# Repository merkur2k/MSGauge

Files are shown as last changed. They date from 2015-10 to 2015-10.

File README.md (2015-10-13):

MegaSquirt CANbus gauge
==================

This is a simple single gauge for the [MegaSquirt](http://www.msextra.com/) Engine Controller.
It connects via CANbus and can output either via a 1.3" OLED display
or a small Switec X25 series stepper motor gauge needle driver.

It is built using the ARM [mbed](https://www.mbed.com/en/) platform, or more specicically a
port of it to GCC - [gcc4mbed](https://github.com/adamgreen/gcc4mbed/).

Quick start:
-----------
```
git clone https://github.com/merkur2k/MSGauge.git
cd MSGauge
git clone https://github.com/adamgreen/gcc4mbed.git
```
Follow the instructions at https://github.com/adamgreen/gcc4mbed/ to build gcc4mbed for your platform.
Build one of the gauge types:
```
cd MSGauge_OLED
make
```
or
```
cd MSGauge_Stepper
make
```
Use an ISP utility such as flash Magic (Windows) or lpc21isp (Linux) to flash the .bin or .hex in the LPC11C24 folder.

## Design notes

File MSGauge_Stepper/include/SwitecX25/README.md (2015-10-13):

Switec X25 library
==================

This is an mbed library for driving Switec X25 miniature
stepper motors. It was written specifically for the Switec X25.168,
and compatible steppers from other manufacturers including the
VID29 and MCR1108.

This was ported from an [Arduino version](https://github.com/clearwater/SwitecX25).

For more information including [datasheets](http://guy.carpenter.id.au/gaugette/resources) see the [Gaugette blog](http://guy.carpenter.id.au/gaugette/).

Usage Notes
-----------
This library assumes you are driving the X25 from any four IO lines,
via an intermediate controller circuit (any dual H-bridge driver).
A motor can be connected to any 4 digital output lines.

The rate at which these miniature stepper motors
can accelerate is dependent upon the inertia
of the needle you are using.  You may need to tune the acceleration
tables in the library for your needle.

This Library Is ASYNCHRONOUS NON-BLOCKING
-----------------------------------------
If you read nothing more, please read and understand this:

The ```update()``` call is _non-blocking_.  It does _NOT_ move
the motor to the target position, it advances the motor _at most
just one step_ toward the target position and returns.

The correct way to use this library asynchronously is:

- Add a call to ```update()``` inside your main loop.  It should be called as frequently as possible.  It will return quickly if there is nothing to be done.  This means for example if you are waiting for serial I/O, you should be calling ```update()``` while you are waiting.

- Call ```setPosition()``` whenever you need to change the target position of the motor.

The advantage of this over a blocking/synchronous library is that you can
control many motors simultanously, and you wont have long periods of inactivity
(and potentially missed I/O events) while your motor is moving.

If instead you require a blocking call which will complete the motor action before returning:

- Call ```setPosition()``` to to the target position of the motore

- Call ```updateBlocking()``` which will move the motor smoothy to the position set by ```setPosition()```.

Using the Library
-----------------

```C++
#include "SwitecX25.h"

// 315 degrees of range = 315x3 steps = 945 steps
// declare motor1 with 945 steps on pins 4-7
SwitecX25 motor1(315*3, P4,P5,P6,P7);

// declare motor2 with 945 steps on pins 8-11
SwitecX25 motor2(315*3, P8,P9,P10,P11);

printf("Go!\r\n");

// run both motors against stops to re-zero
motor1.zero();   // this is a slow, blocking operation
motor2.zero();  
motor1.setPosition(427);
motor2.setPosition(427);

void main(void) {
  // update motors frequently to allow them to step
  motor1.update();
  motor2.update();

  // do stuff, call motorX.setPosition(step) to
  // direct needle to new position.
}

```

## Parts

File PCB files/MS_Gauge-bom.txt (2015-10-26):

Part  Value          Device                Package                     Description                    
B1    ISP            SWITCH_TACT_SMTEVQPQ  BTN_EVQPQ_4.5MM             SMT Tact Switches                  http://www.mouser.com/ProductDetail/Panasonic/EVQ-PQHB55/?qs=%2fha2pyFadujeZOYETOiTVaMULyp0EOOpTFQossK0Vzk%3d
B2    ISP            SWITCH_TACT_SMTEVQPQ  BTN_EVQPQ_4.5MM             SMT Tact Switches                  http://www.mouser.com/ProductDetail/Panasonic/EVQ-PQHB55/?qs=%2fha2pyFadujeZOYETOiTVaMULyp0EOOpTFQossK0Vzk%3d
C1    18pF           CAP_CERAMIC0603       0603                        Ceramic Capacitors                 http://www.mouser.com/ProductDetail/AVX/06035A180GAT2A/?qs=sGAEpiMZZMs0AnBnWHyRQE2IRmxFPR1e1Lyvkz4L%252bhQ%3d
C2    10pF           CAP_CERAMIC0603       0603                        Ceramic Capacitors                 http://www.mouser.com/ProductDetail/AVX/06031C103KAT2A/?qs=sGAEpiMZZMs0AnBnWHyRQE2IRmxFPR1ekNYS%2fLeHWG0%3d
C3    100nF          CAP_CERAMIC0603       0603                        Ceramic Capacitors                 http://www.mouser.com/ProductDetail/AVX/06035C104KAT2A/?qs=sGAEpiMZZMs0AnBnWHyRQE2IRmxFPR1ePtLkvMARri4%3d
C4    10nF           CAP_CERAMIC0603       0603                        Ceramic Capacitors             
C5    100nF          CAP_CERAMIC0603       0603                        Ceramic Capacitors             
C6    10nF           CAP_CERAMIC0603       0603                        Ceramic Capacitors             
C7    10uF           CAP_CERAMIC1206       1206                        Ceramic Capacitors                 http://www.mouser.com/ProductDetail/Murata-Electronics/GCM31CC71E106KA03L/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
C8    10uF           CAP_CERAMIC1206       1206                        Ceramic Capacitors             
D1                   DIODESMA              SMADIODE                    Diode                              http://www.mouser.com/ProductDetail/STMicroelectronics/STTH102AY/?qs=EkbspN8Z2F35MrbgcZPHsw%3d%3d
IC1   B1836M         B1836M                MFP14S                                                         http://www.mouser.com/ProductDetail/ON-Semiconductor/LB1836ML-TLM-E/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
IC2   LPC11C24_QFP48 LPC11C24_QFP48        LQFP48                                                         http://www.mouser.com/ProductDetail/NXP-Semiconductors/LPC11C24FBD48-301/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
IC3   24LC32AT-I/OT  24LC32AT-I/OT         SOT23-5L                                                       http://www.mouser.com/ProductDetail/Microchip-Technology/24LC32AT-I-OT/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
JP1                  HEADER-1X4ROUND       1X04_ROUND                  PIN HEADER for OLED, 2x required   http://www.mouser.com/ProductDetail/Molex/87898-0426/?qs=sGAEpiMZZMs%252bGHln7q6pm8NDWwBzqQCN6n%2fkr6CupYg%3d                    
JP2   ISP            HEADER-1X6SMT         1X06_SMT                    PIN HEADER for ISP serial          http://www.mouser.com/ProductDetail/Molex/87898-0626/?qs=sGAEpiMZZMs%252bGHln7q6pm8NDWwBzqQCN6ivodECCTq8%3d
LED2                 LED0603               CHIPLED_0603                LED     
R1    120            RESISTOR0603          0603                        Resistors                          http://www.mouser.com/ProductDetail/Panasonic/ERJ-3GEYJ121V/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
R2    120            RESISTOR0603          0603                        Resistors                        
R3    10k            RESISTOR0603          0603                        Resistors                        
R4    10k            RESISTOR0603          0603                        Resistors                        
R7    4.7k           RESISTOR0603          0603                        Resistors                        
R8    4.7k           RESISTOR0603          0603                        Resistors  
U$1   VID29-FLIPPED  VID29-FLIPPED         VID29-FLIPPED               Switec X27.168 motor               ebay, etc                
U$18  OLED-SMT       OLED-SMT              OLED-1.3-SMT                Uses 2x 4 pos pin header           http://www.mouser.com/ProductDetail/Molex/87898-0426/?qs=sGAEpiMZZMs%252bGHln7q6pm8NDWwBzqQCN6n%2fkr6CupYg%3d                        
U1                   VREG_SOT23            SOT23-R                     SOT23 Fixed Voltage Regulators     http://www.mouser.com/ProductDetail/Microchip-Technology/MCP1700T-3302E-TT/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
U2    TSR1-2450      TSR1-2450             TSR-1                       Traco Power TSR 1-2450             http://www.mouser.com/ProductDetail/RECOM-Power/R-78E50-05/?qs=sGAEpiMZZMt6Q9lZSPl3Re5VKOUP6OK3oKGplDCSDFs%3d 
Y1    12MHz          CRYSTALTHIN           CRYSTAL_3.2X2.5             Crystals                           http://www.mouser.com/ProductDetail/ABRACON/ABM8G-12000MHZ-B4Y-T/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

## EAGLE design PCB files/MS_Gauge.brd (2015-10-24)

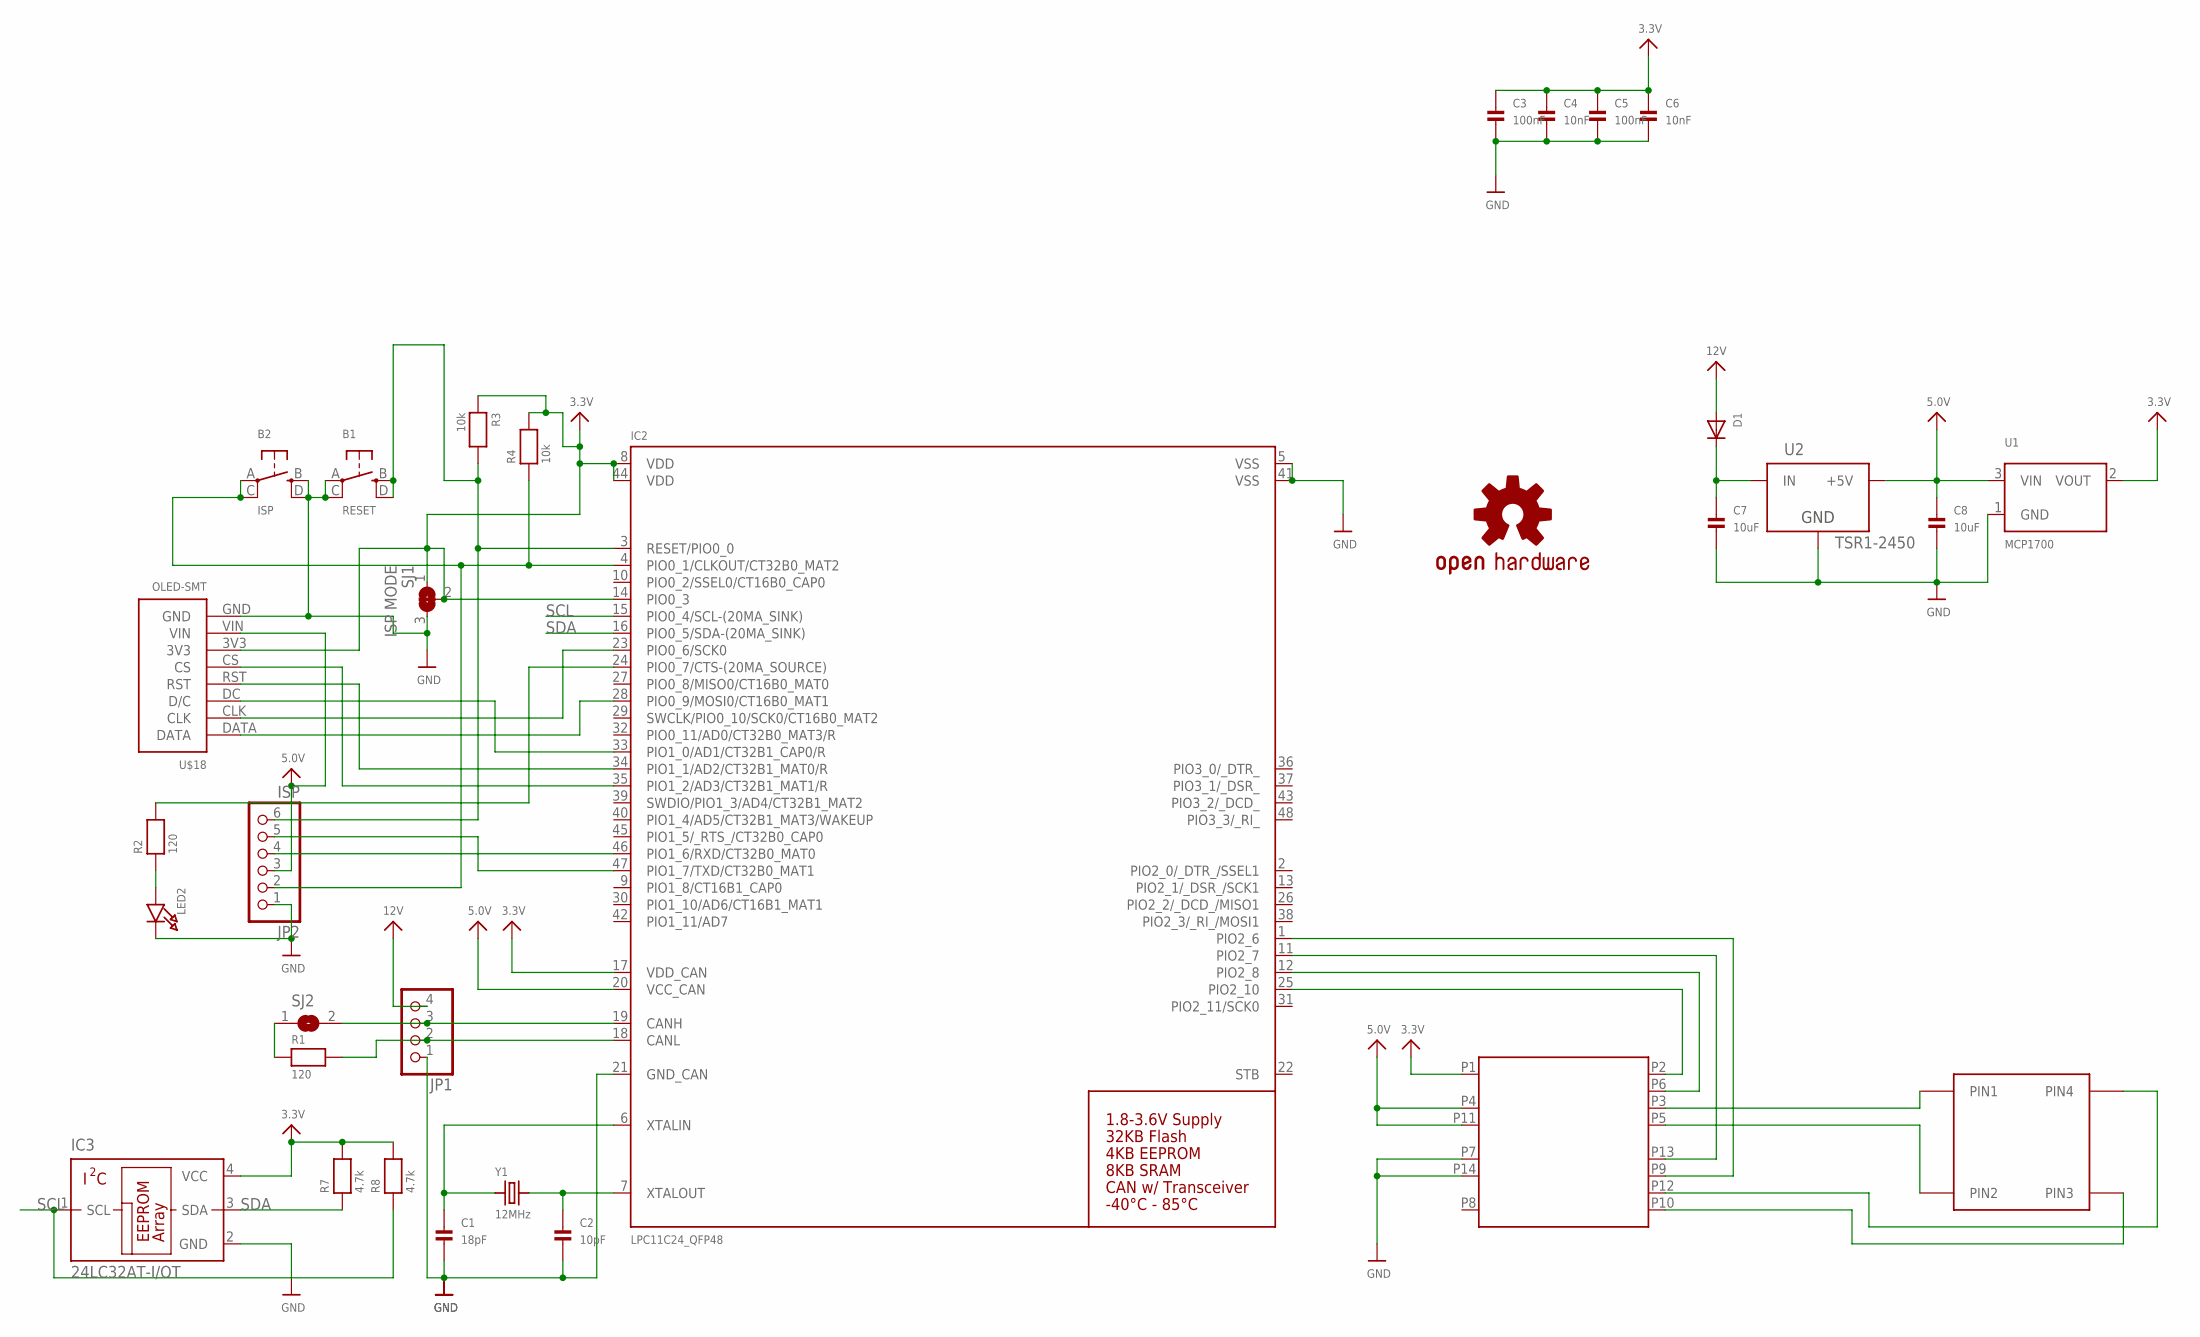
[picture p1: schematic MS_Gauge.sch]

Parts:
B1: RESET; BTN_EVQPQ_4.5MM
B2: ISP; BTN_EVQPQ_4.5MM
C1: 18pF; 0603
C2: 10pF; 0603
C3, C5: 100nF; 0603
C4, C6: 10nF; 0603
C7, C8: 10uF; 1206
D1: DIODESMA; SMADIODE
IC1: B1836M; MFP14S
IC2: LPC11C24_QFP48; LQFP48
IC3: 24LC32AT-I/OT; SOT23-5L
JP1: HEADER-1X4ROUND; 1X04_ROUND
JP2: ISP; 1X06_SMT
LED2: LED0603; CHIPLED_0603
LOGO1: OSHW-LOGOL; OSHW-LOGO-L
R1, R2: 120; 0603
R3, R4: 10k; 0603
R7, R8: 4.7k; 0603
SJ1: ISP MODE; SOLDERJUMPER_2WAY_OPEN_0805
SJ2: SOLDERJUMPER; SOLDERJUMPER_ARROW_NOPASTE
U1: MCP1700; SOT23-R
U2: TSR1-2450; TSR-1
U$1: VID29-FLIPPED
U$18: OLED-SMT; OLED-1.3-SMT
Y1: 12MHz; CRYSTAL_3.2X2.5

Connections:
3.3V: C3.1, C4.1, C5.1, C6.1, IC1.P1 (VCC), IC2.8 (VDD), IC2.14 (PIO0_3), IC2.17 (VDD_CAN), IC2.44 (VDD), IC3.4 (VCC), R3.1, R4.2, R7.2, R8.2, SJ1.1, SJ1.2, U1.2 (VOUT), U$18.3V3
5.0V: C8.1, IC1.P4 (VS1), IC1.P11 (VS2), IC2.20 (VCC_CAN), JP2.3, U1.3 (VIN), U2.3 (+5V), U$18.VIN
12V: D1.A, JP1.4
GND: B1.A, B1.C (P1), B2.B (S), B2.D (S1), C1.2, C2.2, C3.2, C4.2, C5.2, C6.2, C7.2, C8.2, IC1.P7 (GND1), IC1.P14 (GND2), IC2.5 (VSS), IC2.21 (GND_CAN), IC2.41 (VSS), IC3.2 (GND), JP1.1, JP2.1, LED2.C, SJ1.3, U1.1 (GND), U2.2 (GND), U$18.GND
unnamed: R1.1, SJ2.1
unnamed: IC2.18 (CANL), JP1.2, R1.2
unnamed: C2.1, IC2.7 (XTALOUT), Y1.2
unnamed: C1.1, IC2.6 (XTALIN), Y1.1
unnamed: B2.A, B2.C (P1), IC2.4 (PIO0_1/CLKOUT/CT32B0_MAT2), JP2.2, R4.1
unnamed: IC1.P2 (IN1), IC2.25 (PIO2_10)
unnamed: B1.B (S), B1.D (S1), IC2.3 (RESET/PIO0_0), JP2.6, R3.2
unnamed: IC1.P13 (IN3), IC2.11 (PIO2_7)
unnamed: IC1.P9 (IN4), IC2.1 (PIO2_6)
unnamed: IC1.P3 (OUT1), U$1.PIN1
unnamed: C7.1, D1.C, U2.1 (IN)
unnamed: IC1.P5 (OUT2), U$1.PIN2
unnamed: IC1.P12 (OUT3), U$1.PIN4
unnamed: IC1.P10 (OUT4), U$1.PIN3
unnamed: IC2.19 (CANH), JP1.3, SJ2.2
unnamed: IC2.46 (PIO1_6/RXD/CT32B0_MAT0), JP2.4
unnamed: IC2.47 (PIO1_7/TXD/CT32B0_MAT1), JP2.5
unnamed: IC2.28 (PIO0_9/MOSI0/CT16B0_MAT1), U$18.DATA
unnamed: IC2.33 (PIO1_0/AD1/CT32B1_CAP0/R), U$18.DC (D/C)
unnamed: IC2.34 (PIO1_1/AD2/CT32B1_MAT0/R), U$18.RST
unnamed: IC2.23 (PIO0_6/SCK0), U$18.CLK
unnamed: IC2.35 (PIO1_2/AD3/CT32B1_MAT1/R), U$18.CS
unnamed: IC2.24 (PIO0_7/CTS-(20MA_SOURCE)), R2.2
unnamed: LED2.A, R2.1
unnamed: IC1.P6 (IN2), IC2.12 (PIO2_8)
SCL: IC2.15 (PIO0_4/SCL-(20MA_SINK)), IC3.1 (SCL), R8.1
SDA: IC2.16 (PIO0_5/SDA-(20MA_SINK)), IC3.3 (SDA), R7.1

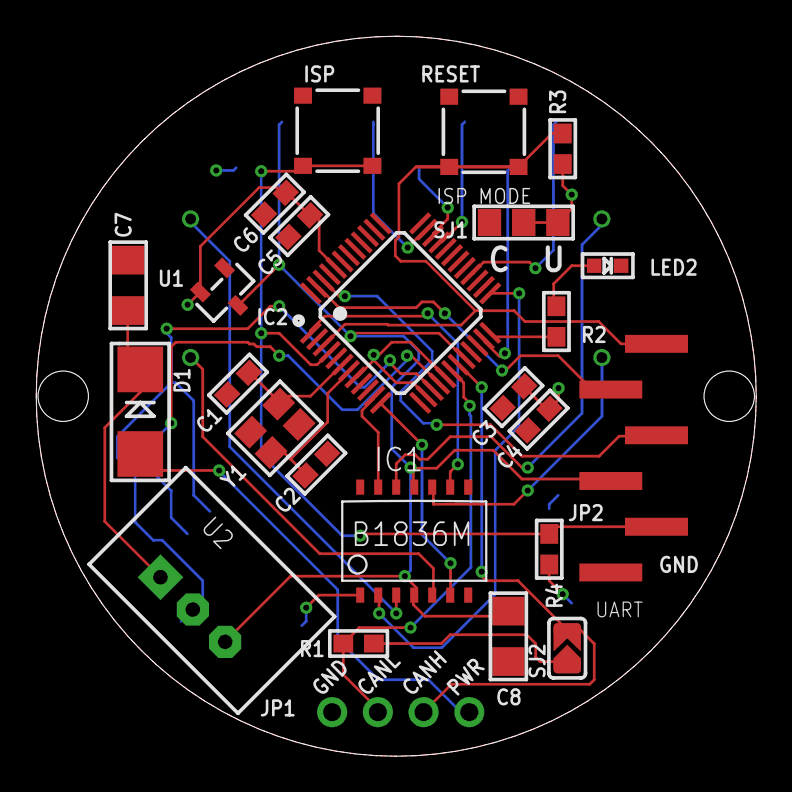
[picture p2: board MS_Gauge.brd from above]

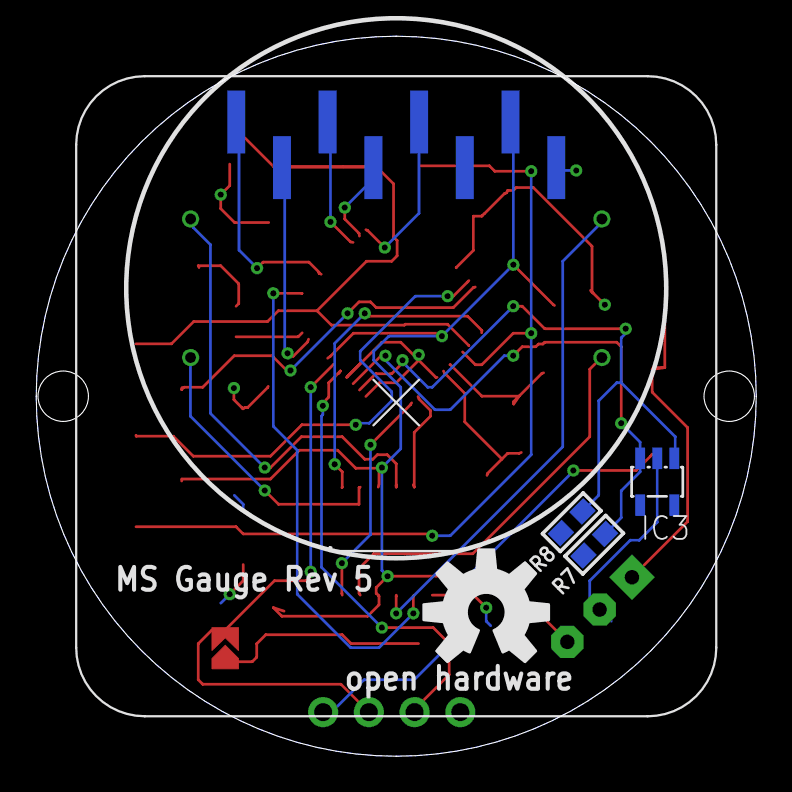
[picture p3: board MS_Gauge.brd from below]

Board: 2 copper layers, 40.0 x 40.0 mm, 31 parts (6 on the bottom side), 31 nets.

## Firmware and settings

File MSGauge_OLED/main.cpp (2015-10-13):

/*
 *  Copyright (c) 2015 Jason Richardson
 *
 *  License: MIT open source (http://opensource.org/licenses/MIT)
 *      Summary;
 *      Use / modify / distribute / publish it how you want and
 *      if you use it, or don't, you can't hold me liable for how
 *      it does or doesn't work.
 *      If it doesn't work how you want, don't use it, or change
 *      it so that it does work.
 */

#include "mbed.h"
#include "Gauge_config.h"
#include "include/SSD1306/Adafruit_SSD1306.h"

uint16_t value = 1;
Timer alarmTimer;
Timer commTimer;
Timer displayTimer;

#if defined(GAUGE_MAP)
uint16_t baro = 0;
#endif

char tempchars[11];

bool connectionState = true;
bool alarmDisplayStatus = false;

DigitalOut led2(LED2);
CAN can1(p9, p10);

// an SPI sub-class that provides a constructed default
class SPIPreInit : public SPI
{
public:
    SPIPreInit(PinName mosi, PinName miso, PinName clk) : SPI(mosi,miso,clk)
    {
        format(8,3);
        frequency(4000000);
    };
};

SPIPreInit gSpi(P0_9,P0_8,P0_6);
//                             DC,  RST, CS
Adafruit_SSD1306_Spi oled(gSpi,P1_0,P1_1,P1_2,64,128);

void divby10(int val) {
  uint8_t length;

  itoa(val, tempchars, 10);
  length=strlen(tempchars);

  tempchars[length + 1]=tempchars[length]; // null shift right
  tempchars[length]=tempchars[length - 1]; //
  tempchars[length - 1]='.';
}

// CAN receive interrupt handler
void canRX() {
  CANMessage msg;
  while(can1.read(msg)) {
    if (msg.id == 1522) {
      connectionState = true;
      commTimer.reset();
#if defined(GAUGE_CLT)
      value = msg.data[7] | (msg.data[6] << 8);
#elif defined(GAUGE_MAT)
      value = msg.data[5] | (msg.data[4] << 8);
#elif defined(GAUGE_MAP)
      value = msg.data[3] | (msg.data[2] << 8);
      baro = msg.data[1] | (msg.data[0] << 8);
#endif
      led2 = !led2;
    }
  }
}

void drawGauge(void) {
  oled.drawLine(0, 12, 12, 22, WHITE);
  oled.drawLine(20, 12, 28, 22, WHITE);
  oled.drawLine(40, 12, 45, 22, WHITE);
  oled.drawLine(88, 12, 83, 22, WHITE);
  oled.drawLine(108, 12, 100, 22, WHITE);
  oled.drawLine(128, 12, 116, 22, WHITE);
  oled.drawFastVLine(64, 12, 10, WHITE);

  oled.setTextSize(1);
  oled.setTextColor(WHITE);
#if defined(GAUGE_CLT)
  oled.setTextCursor(44,27);
  oled.printf("COOLANT");
  oled.setTextCursor(32,36);
  oled.printf("TEMPERATURE");
  oled.setTextCursor(0,0);
  oled.printf("COLD");
  oled.setTextCursor(47,0);
  oled.printf("NORMAL");
  oled.setTextCursor(110,0);
  oled.printf("HOT");
#elif defined(GAUGE_MAP)
  oled.setTextCursor(40,27);
  oled.printf("MANIFOLD");
  oled.setTextCursor(40,36);
  oled.printf("PRESSURE");
  oled.setTextCursor(0,0);
  oled.printf("0");
  oled.setTextCursor(60,0);
  oled.printf("10");
  oled.setTextCursor(116,0);
  oled.printf("20");
#endif
}

void drawNeedle(uint16_t value) {
  uint8_t level;
  uint16_t alarmValue = 0;

  // scale "value" to 1-128 and store it in "level", and set bounds for error condition
  // value * 128 / full_scale
#if defined(GAUGE_CLT)
  //value /= 10;
  // scale 160-260, alarm > 230
  if (value >= 1600) {
    level = (value / 10 - 160) * 128 / 70;
  } else {
    level = 0;
  }
  alarmValue = 2300;
  oled.setTextSize(2);
  oled.setTextCursor(36,48);
  //oled.printf("%4d.%1d",value/10,value%10);
#elif defined(GAUGE_MAT)
  value /= 10;
  if (value >= 160) {
    level = (value - 160) * 128 / 70;
  } else {
    level = 0;
  }
  oled.setTextSize(2);
  oled.setTextCursor(36,48);
  //oled.printf("%4d.%1d",value/10,value%10);
  divby10(value);
  oled.printf("%s",tempchars);

#elif defined(GAUGE_MAP)
  // assume 2.5 bar MAP sensor with forced induction
  // needle scales for boost only, 0-21ish psi
  if (value > baro) {
    // in boost. 6.895kpa = 1psi
    value = (value - baro) * 200 / 1379;
    level = value * 128 / 210;
    oled.setTextSize(2);
    oled.setTextCursor(52,48);
    //oled.printf("%2d.%1d",value/10,value%10);
    divby10(value);
    oled.printf("%s",tempchars);
    oled.setTextSize(1);
    oled.setTextCursor(104,56);
    oled.printf("psi");
  } else {
    // in vacuum. 1 kPa = 0.2953 in Hg
    level = 0;
    value = abs(baro - value) * 2953 / 10000;
    oled.setTextSize(2);
    oled.setTextCursor(0,48);
    //oled.printf("%2d.%1d",value/10,value%10);
    divby10(value);
    oled.printf("%s",tempchars);
    oled.setTextSize(1);
    oled.setTextCursor(52,56);
    oled.printf("in/Hg");
  }
#endif
  if (level > 128) level = 128;
  oled.drawLine(level,  6, 62,64, WHITE, 45);
  oled.drawLine(level+1,6, 63,64, WHITE, 45);
  oled.drawLine(level+2,6, 64,64, WHITE, 45);



  // "flash" the display (invert) during error condition
  if (alarmDisplayStatus && alarmValue > 0 && value > alarmValue) {
    oled.invertDisplay(true);
  } else {
    oled.invertDisplay(false);
  }
}

void updateGauge(void) {
  drawGauge();
  drawNeedle(value);
  oled.display();
  oled.clearDisplay();
}

int main() {
  commTimer.start();
  alarmTimer.start();
  displayTimer.start();
  printf("Initializing...\r\n");
  can1.frequency(500000);

  oled.clearDisplay();
  oled.display();
//wait(3);
  updateGauge();

  can1.attach(canRX);

  while(1) {
    // detect error conditions and toggle a bit to be used by display routines
    if (alarmTimer.read_ms() > 500) {
      alarmDisplayStatus = !alarmDisplayStatus;
      alarmTimer.reset();
    }

    // see if we have gotten any CAN messages in the last second. display an error if not
    if (commTimer.read_ms() > 1000) {
      commTimer.reset();
      connectionState = false;
    }

    if (!connectionState && alarmDisplayStatus) {
      oled.setTextSize(1);
      oled.setTextColor(WHITE);
      oled.setTextCursor(0,56);
      oled.printf("No data");
    }

    if (displayTimer.read_ms() > 100) {
      displayTimer.reset();
      updateGauge();
    }
  }
}

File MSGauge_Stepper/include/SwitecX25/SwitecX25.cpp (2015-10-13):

/*
 *  SwitecX25 Arduino Library
 *  Guy Carpenter, Clearwater Software - 2012
 *
 *  Licensed under the BSD2 license, see license.txt for details.
 *
 *  All text above must be included in any redistribution.
 */
#include "mbed.h"
#include "SwitecX25.h"

// During zeroing we will step the motor CCW
// with a fixed step period defined by RESET_STEP_MICROSEC
#define RESET_STEP_MICROSEC 800

// This table defines the acceleration curve.
// 1st value is the speed step, 2nd value is delay in microseconds
// 1st value in each row must be > 1st value in subsequent row
// 1st value in last row should be == maxVel, must be <= maxVel
static unsigned short defaultAccelTable[][2] = {
  {   20, 3000},
  {   50, 1500},
  {  100, 1000},
  {  150,  800},
  {  300,  600}
};
#define DEFAULT_ACCEL_TABLE_SIZE (sizeof(defaultAccelTable)/sizeof(*defaultAccelTable))

// experimentation suggests that 400uS is about the step limit
// with my hand-made needles made by cutting up aluminium from
// floppy disk sliders.  A lighter needle will go faster.

// State  3 2 1 0   Value
// 0      1 0 0 1   0x9
// 1      0 0 0 1   0x1
// 2      0 1 1 1   0x7
// 3      0 1 1 0   0x6
// 4      1 1 1 0   0xE
// 5      1 0 0 0   0x8
static uint8_t stateMap[] = {0x9, 0x1, 0x7, 0x6, 0xE, 0x8};

SwitecX25::SwitecX25(unsigned int steps, PinName pin1, PinName pin2, PinName pin3, PinName pin4)
{
  this->currentState = 0;
  this->steps = steps;
  this->pins[0] = new DigitalOut(pin1, false);
  this->pins[1] = new DigitalOut(pin2, false);
  this->pins[2] = new DigitalOut(pin3, false);
  this->pins[3] = new DigitalOut(pin4, false);

  dir = 0;
  vel = 0;
  stopped = true;
  currentStep = 0;
  targetStep = 0;

  accelTable = defaultAccelTable;
  maxVel = defaultAccelTable[DEFAULT_ACCEL_TABLE_SIZE-1][0]; // last value in table.
  this->stepTimer.start();
}

void SwitecX25::writeIO()
{

  uint8_t mask = stateMap[currentState];
  for (int i=0;i<pinCount;i++) {
    pins[i]->write(mask & 0x1?1:0);
    mask >>= 1;
  }
}

void SwitecX25::stepUp()
{
  if (currentStep < steps) {
    currentStep++;
    currentState = (currentState + 1) % stateCount;
    writeIO();
  }
}

void SwitecX25::stepDown()
{
  if (currentStep > 0) {
    currentStep--;
    currentState = (currentState + 5) % stateCount;
    writeIO();
  }
}

void SwitecX25::zero()
{
  currentStep = steps - 1;
  for (unsigned int i=0;i<steps;i++) {
    stepDown();
    wait_us(RESET_STEP_MICROSEC);
  }
  currentStep = 0;
  targetStep = 0;
  vel = 0;
  dir = 0;
}

// This function determines the speed and accel
// characteristics of the motor.  Ultimately it
// steps the motor once (up or down) and computes
// the delay until the next step.  Because it gets
// called once per step per motor, the calcuations
// here need to be as light-weight as possible, so
// we are avoiding floating-point arithmetic.
//
// To model acceleration we maintain vel, which indirectly represents
// velocity as the number of motor steps travelled under acceleration
// since starting.  This value is used to look up the corresponding
// delay in accelTable.  So from a standing start, vel is incremented
// once each step until it reaches maxVel.  Under deceleration
// vel is decremented once each step until it reaches zero.

void SwitecX25::advance()
{
  stepTimer.reset();

  // detect stopped state
  if (currentStep==targetStep && vel==0) {
    stopped = true;
    dir = 0;
    vel = 0;
    return;
  }

  // if stopped, determine direction
  if (vel==0) {
    dir = currentStep<targetStep ? 1 : -1;
    // do not set to 0 or it could go negative in case 2 below
    vel = 1;
  }

  if (dir>0) {
    stepUp();
  } else {
    stepDown();
  }

  // determine delta, number of steps in current direction to target.
  // may be negative if we are headed away from target
  int delta = dir>0 ? targetStep-currentStep : currentStep-targetStep;

  if (delta>0) {
    // case 1 : moving towards target (maybe under accel or decel)
    if (delta < vel) {
      // time to declerate
      vel--;
    } else if (vel < maxVel) {
      // accelerating
      vel++;
    } else {
      // at full speed - stay there
    }
  } else {
    // case 2 : at or moving away from target (slow down!)
    vel--;
  }

  // vel now defines delay
  unsigned char i = 0;
  // this is why vel must not be greater than the last vel in the table.
  while (accelTable[i][0]<vel) {
    i++;
  }
  microDelay = accelTable[i][1];
}

void SwitecX25::setPosition(unsigned int pos)
{
  // pos is unsigned so don't need to check for <0
  if (pos >= steps) pos = steps-1;
  targetStep = pos;
  if (stopped) {
    // reset the timer to avoid possible time overflow giving spurious deltas
    stopped = false;
    stepTimer.reset();
    microDelay = 0;
  }
}

void SwitecX25::update()
{
  if (!stopped) {
    if (stepTimer.read_us() >= microDelay) {
      advance();
    }
  }
}


//This updateMethod is blocking, it will give you smoother movements, but your application will wait for it to finish
void SwitecX25::updateBlocking()
{
  while (!stopped) {
    if (stepTimer.read_us() >= microDelay) {
      advance();
    }
  }
}

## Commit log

2015-10-13 Add stepper motor version
2015-10-13 Further reorginization and initial commit of stepper version
2015-10-13 Adding Stepper gauge code
2015-10-13 Add PCB artwork Eagle files
    [MS_Gauge.brd, MS_Gauge.sch]
2015-10-19 Update Eagle files to Rev 4. Fixes wrong reset button wiring, adds termination resistor solder jumper.
    [MS_Gauge.brd, MS_Gauge.sch]
2015-10-19 Update Eagle files to Rev 5. Adds i2c eeprom.
    [MS_Gauge.brd, MS_Gauge.sch]
2015-10-24 Minor routing changes to PCB
    [MS_Gauge.brd, MS_Gauge.sch]
2015-10-24 Add basic BOM
2015-10-26 BOM updates

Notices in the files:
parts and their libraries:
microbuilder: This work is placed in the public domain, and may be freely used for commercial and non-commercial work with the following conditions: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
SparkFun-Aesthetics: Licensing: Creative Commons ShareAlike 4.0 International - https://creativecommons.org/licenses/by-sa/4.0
